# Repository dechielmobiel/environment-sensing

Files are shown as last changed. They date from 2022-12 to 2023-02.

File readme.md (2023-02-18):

<p align="center">
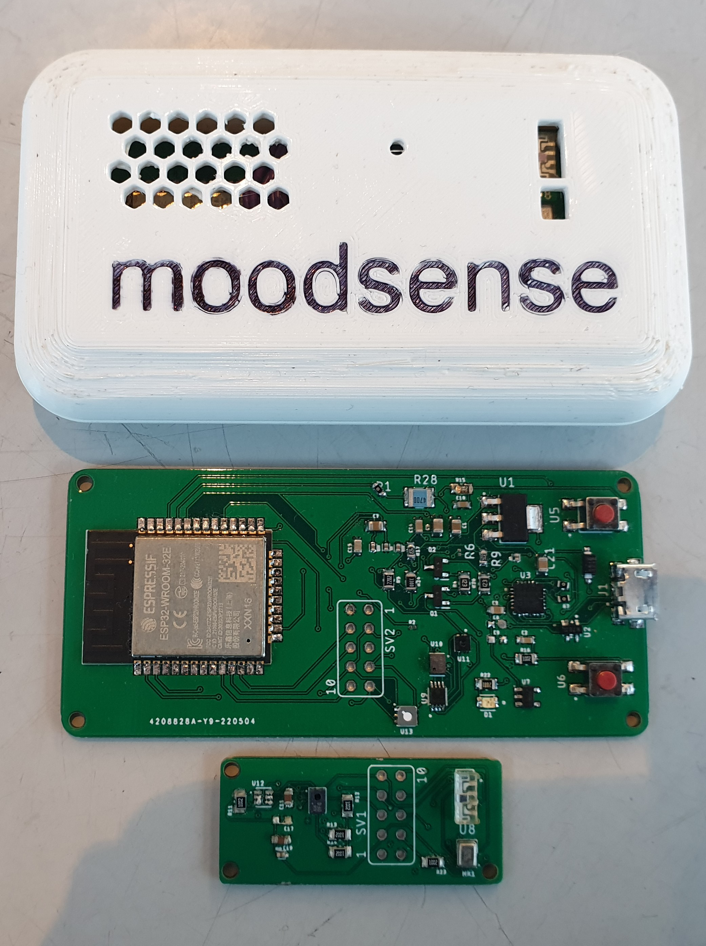
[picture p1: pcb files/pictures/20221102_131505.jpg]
  
</p>

# Environment-sensing
this repository contains all the code and hardware designs for a environmental sensing device that measures environmental paramaters like: illuminance, VOC's, Co2, 11 channel collour, sound, humdidity, temperature and atmospheric pressure, then you can employ tinyML to classify some data with Edge impulse or use a tensorflow model.
# Repesitory contents
- bill of materials 💸
- code 📄
  - Tensorflow Lite
  - Edge impulse
  - Luxpy
  - BLE
  - ESPhome
- mechanical drawings 🔧
  - STL files
  - render pictures
- pcb files 🔋
  - Gerber files
  - project files (schematic + board)
# Prerequisites 
# Hardware
- arduino nano 33 ble sense or ESP32 devkit or ESP-EYE v2.2
- Raspberry pi or linux enabled device 
- Used sensors
  - AS7341 (10 channel color sensor)
  - VEML7700 (lux sensor)
  - SGP30 (Co2 and VOC sensor)
  - DPS310 (air pressure sensor)
  - SHTC3 (temperature and humidity sensor)
  - SPH0645LM4H-1 (I2S mems microphone)
# Software 
- edge impulse cli
- Python (latest stable version)
- tensorflow 2.11
- Jupyter notebook or Jupyter labs
- IDE of choice
  - esp idf (in the case of Tensorflow this is required for use with ESP eye)
  - arduino ide 
  - visual studio code
- git bash
- NumPy
- TensorFlow Hub
- Tensorflow_io 0.28
- nrf connect (Android or IOS)
- (optional)
  - ESPhome
  - Home assistant 
  - InfluxdB
# Edge impulse public projects
- sound classification with ESC-50 (requires a I2S microphone): https://studio.edgeimpulse.com/public/126166/latest/create-impulse
- classify the type of light ( requires AS7341 sensor): https://studio.edgeimpulse.com/studio/54747
# Use esp to capture datapoints for edge impulse
first upload the ...data_aquisition code for example (AS7341_data_aquisition).this code can be editted for your specific sensor.
Then open a commandprompt with edge impulse cli installed and type in the following command.
```cmd
edge-impulse-data-fowarder
```
then the cli will ask you to login to your edge impulse account.
next the cli will ask to wich project you want to connect the device, this can be done by using the arrowkeys.
after this the cli will detect the ammount of sensor axis from the code and asks you to name them, sperated by a comma 
(this has to be done in the exact same order as in the code). 

now you can build your impulse 

# deploy the impulse on a esp32 
the code for the deployment of your impulse on esp32 (or other adruino enabled devices) is based on the data forwarder code and can be modified to work with your sensor just as in the aquisition. To change or upgrade the model you only have to change the inference include file.
here is a example of the code for the AS7341.
```c++
// Include the Arduino library here (something like your_project_inference.h) 
// In the Arduino IDE see **File > Examples > Your project name - Edge Impulse > Static buffer** to get the exact name
#include <zonlicht_vs_kunstlicht_inferencing.h>
#include <Adafruit_AS7341.h>

#define FREQUENCY_HZ        (2)
#define INTERVAL_MS         (1000 / (FREQUENCY_HZ + 1))

Adafruit_AS7341 as7341;
static unsigned long last_interval_ms = 0;
// to classify 1 frame of data you need EI_CLASSIFIER_DSP_INPUT_FRAME_SIZE values
float features[EI_CLASSIFIER_DSP_INPUT_FRAME_SIZE];
// keep track of where we are in the feature array
size_t feature_ix = 0;

void setup() {
    Serial.begin(115200);
    Serial.println("Started");

    if (!as7341.begin()) {
        Serial.println("Failed to initialize AS7341!");
        while (1);
    }
}

void loop() {
    uint16_t readings[12];

    if (millis() > last_interval_ms + INTERVAL_MS) {
        last_interval_ms = millis();

        // read sensor data in exactly the same way as in the Data Forwarder example
         if (!as7341.readAllChannels(readings)){
         Serial.println("Error reading all channels!");
         return;
         }

        // fill the features buffer
        features[feature_ix++] = (readings[0]);
        features[feature_ix++] = (readings[1]);
        features[feature_ix++] = (readings[2]);
        features[feature_ix++] = (readings[3]);
        features[feature_ix++] = (readings[6]);
        features[feature_ix++] = (readings[7]);
        features[feature_ix++] = (readings[8]);
        features[feature_ix++] = (readings[9]);
        features[feature_ix++] = (readings[11]);

        // features buffer full? then classify!
        if (feature_ix == EI_CLASSIFIER_DSP_INPUT_FRAME_SIZE) {
            ei_impulse_result_t result;

            // create signal from features frame
            signal_t signal;
            numpy::signal_from_buffer(features, EI_CLASSIFIER_DSP_INPUT_FRAME_SIZE, &signal);

            // run classifier
            EI_IMPULSE_ERROR res = run_classifier(&signal, &result, false);
            ei_printf("run_classifier returned: %d\n", res);
            if (res != 0) return;

            // print predictions
            ei_printf("Predictions (DSP: %d ms., Classification: %d ms., Anomaly: %d ms.): \n",
                result.timing.dsp, result.timing.classification, result.timing.anomaly);

            // print the predictions
            for (size_t ix = 0; ix < EI_CLASSIFIER_LABEL_COUNT; ix++) {
                ei_printf("%s:\t%.5f\n", result.classification[ix].label, result.classification[ix].value);
            }
        #if EI_CLASSIFIER_HAS_ANOMALY == 1
            ei_printf("anomaly:\t%.3f\n", result.anomaly);
        #endif

            // reset features frame
            feature_ix = 0;
        }
    }
}

void ei_printf(const char *format, ...) {
    static char print_buf[1024] = { 0 };

    va_list args;
    va_start(args, format);
    int r = vsnprintf(print_buf, sizeof(print_buf), format, args);
    va_end(args);

    if (r > 0) {
        Serial.write(print_buf);
    }
}

```
# test the deployment code
to test of the model and code is correct open the static_buffer example in your generated library.
next go to your model in the web editor for example at live classification and load a validated sample and go to detailed results copy the raw feature to paste in the following line of the code:
```c++
static const float features[] = {
    -19.8800, -0.6900, 8.2300, -17.6600, -1.1300, 5.9700, ...
};
```
after this compare the result of the code to the model and if the same the code is working correctly.

# how to use a Tensorflow Lite model on edge devices.
for a full tutorial check the how to use tensorflow with c++.ipynb file for a tutorial on how to use a simple "Hello World" example model and convert it to a C++ tflite model. The example model that uses the ESC-50 dataset to classify cat and dog sounds can be found in the ESC-50.ipynb file.

after you have confirmed this model to be working substitute the model with the sound classifaction model.
To import the ESC-50 model use the following lines. 
```python
_ = tf.keras.utils.get_file('esc-50.zip',
                        'https://github.com/karoldvl/ESC-50/archive/master.zip',
                        cache_dir='./',
                        cache_subdir='datasets',
                        extract=True)
```
allow the model to explore the dataset with the following lines.
```python
esc50_csv = './datasets/ESC-50-master/meta/esc50.csv'
base_data_path = './datasets/ESC-50-master/audio/'

pd_data = pd.read_csv(esc50_csv)
pd_data.head()
```
Lastly choose the labels/classes you want to use and specify the correct class id which can be found in the metadata file in the ESC-50 directory.
for example the class id's for the classes i used are: 
```python
my_classes = ['coughing', 'snoring','sneezing', 'vacuum cleaner', 'train', 'thunderstorm' ]
map_class_to_id = {'coughing':24, 'snoring':28, 'sneezing':21, 'vacuum cleaner':36, 'train':45, 'thunderstorm':19}
```
If you want to use my classes copy and paste the lines above in the ESC-50 example lines below. 
```python
my_classes = ['dog', 'cat']
map_class_to_id = {'dog':0, 'cat':1}

filtered_pd = pd_data[pd_data.category.isin(my_classes)]

class_id = filtered_pd['category'].apply(lambda name: map_class_to_id[name])
filtered_pd = filtered_pd.assign(target=class_id)

full_path = filtered_pd['filename'].apply(lambda row: os.path.join(base_data_path, row))
filtered_pd = filtered_pd.assign(filename=full_path)

filtered_pd.head(10)
```
# how to convert the Tensorflow yamnet model to a tensorflow Lite model.
```python
# Convert the model to the TensorFlow Lite format without quantization
converter = tf.lite.TFLiteConverter.from_saved_model(MODEL_TF)
model_no_quant_tflite = converter.convert()

# Save the model to disk
open(MODEL_NO_QUANT_TFLITE, "wb").write(model_no_quant_tflite)

# Convert the model to the TensorFlow Lite format with quantization
def representative_dataset():
  for i in range(500):
    yield([x_train[i].reshape(1, 1)])
# Set the optimization flag.
converter.optimizations = [tf.lite.Optimize.DEFAULT]
# Enforce integer only quantization
converter.target_spec.supported_ops = [tf.lite.OpsSet.TFLITE_BUILTINS_INT8]
converter.inference_input_type = tf.int8
converter.inference_output_type = tf.int8
# Provide a representative dataset to ensure we quantize correctly.
converter.representative_dataset = representative_dataset
model_tflite = converter.convert()

# Save the model to disk
open(MODEL_TFLITE, "wb").write(model_tflite)
```
After this compare the result of the newly generated model to the original see: https://github.com/dechielmobiel/environment-sensing/blob/main/how%20to%20use%20tensorflow%20with%20c%2B%2B.ipynb for more information. 
# how to convert the model to Tensorflow Lite C++ library.
Convert the TensorFlow Lite quantized model into a C source file that can be loaded by TensorFlow Lite for Microcontrollers.

```python
# Install xxd if it is not available
!apt-get update && apt-get -qq install xxd
# Convert to a C source file, i.e, a TensorFlow Lite for Microcontrollers model
!xxd -i {MODEL_TFLITE} > {MODEL_TFLITE_MICRO}
# Update variable names
REPLACE_TEXT = MODEL_TFLITE.replace('/', '_').replace('.', '_')
!sed -i 's/'{REPLACE_TEXT}'/g_model/g' {MODEL_TFLITE_MICRO} 
```
# deploy your model 
To use your model with ESP32 run the folowing commands:
```python
make -f tensorflow/lite/micro/tools/make/Makefile third_party_downloads
make -f tensorflow/lite/micro/tools/make/Makefile "your_model.cc"
```

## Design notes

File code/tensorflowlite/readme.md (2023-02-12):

To get Tensorflow Lite running on a ESP32 follow the tutorial to on how use the "Hello World" example on microcontrollers see: (how to setup hello world example and convert to C++.ipynb).

Once this is working move on to use the Yamnet sound classification model and how to use it with the ESC-50 datset see: (ESC-50.ipynb).

To change the classes you want to use see the tutorial in the main readme.

the classes that can be used can be found in the ESC-50 metadata file.

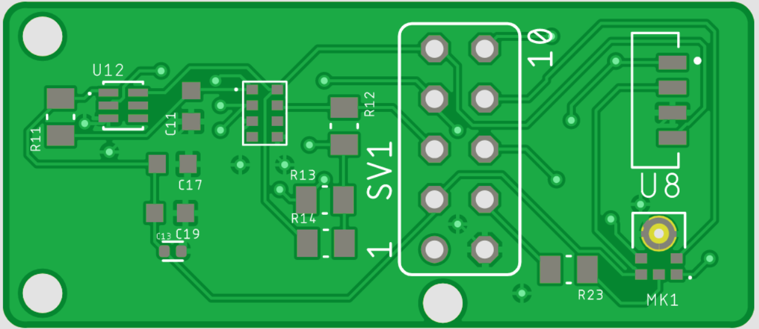
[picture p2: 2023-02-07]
pcb files/pictures/board 2.1.PNG

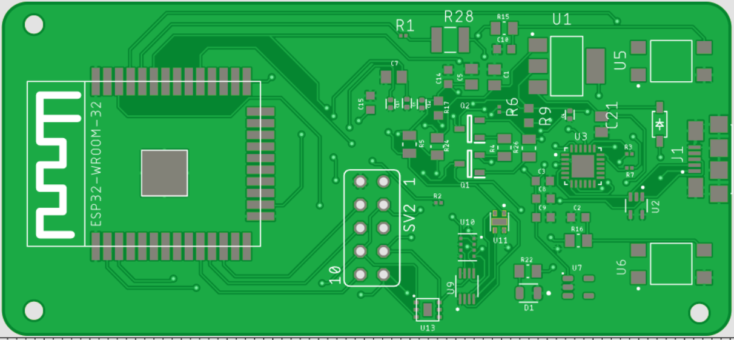
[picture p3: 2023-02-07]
pcb files/pictures/board 3.1.PNG

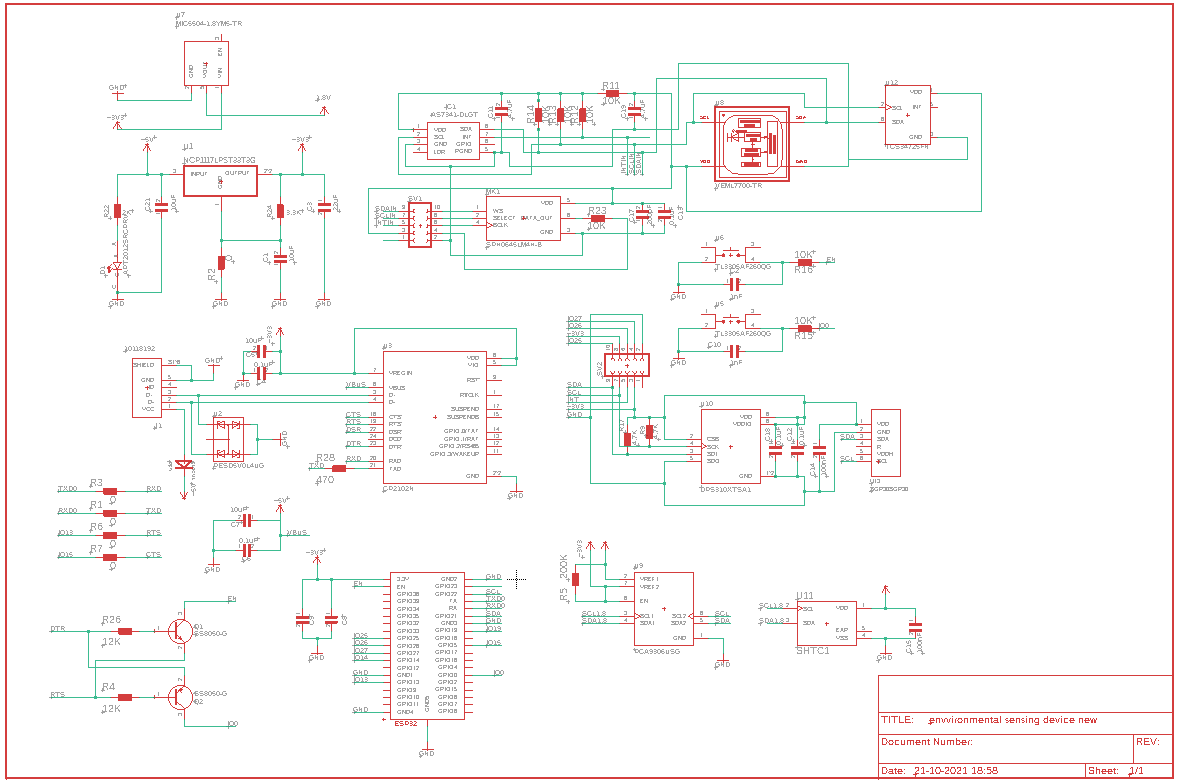
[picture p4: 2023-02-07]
pcb files/pictures/eigen pcb schema.PNG

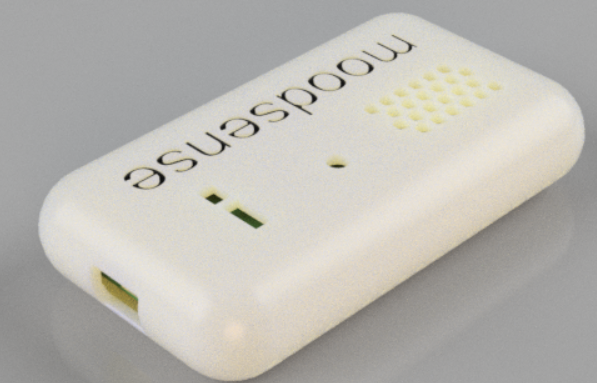
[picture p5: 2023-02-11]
cad files/photo's/isometrisch behuizing.PNG

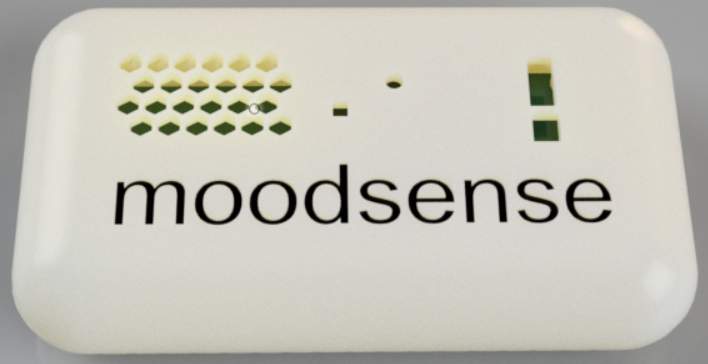
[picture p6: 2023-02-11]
cad files/photo's/moosense behuizing.PNG

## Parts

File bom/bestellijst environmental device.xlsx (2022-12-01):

component | functie | smd/tht | montagetype | stuk prijs | aantal | totaal prijs
AS7341-DLGT | spd meting | smd | OLGA-8 | €6.830 | 5 | €34.15
DPS310XTSA1 | luchtdruk meting | smd | LGA-8 | €3.190 | 5 | €15.95
SHTC3-10k | temperatuur & luchtvochtigheid | smd | DFN-4 | €2.940 | 5 | €14.70
VEML7700-TT | lux meting | smd | SMT | €1.940 | 5 | €9.70
SGP30-2.5k | VOC en Eco2 metingen | smd | DFN-6 | €12.500 | 5 | €62.50
SPH0641LM4H-1 | microfoon | smd | QFN | €0.855 | 5 | €4.28
PESD5V0L4UG,115 | electronic discharge onderdrukking | smd | TSSOP-5 | €0.428 | 5 | €2.14
PCA9306USG | I2C level shifter 3.3v-1.8v, 100Kbit/s - 400Kbit/s | smd | US-8 | €0.840 | 5 | €4.20
SS8050-G | biplolaire transisoren | smd | SOT-23-3 | €0.190 | 10 | €1.90
ESP32-WROOM-32E-N8 | microcontroller + bluetooth & wifi interface | smd | QFN | €3.000 | 5 | €15.00
NCP1117LPST33T3G | voltage regulator 3.3V | smd | SOT-223-3 | €0.420 | 5 | €2.10
MIC5504-1.8YM5-TR | voltage regulator 1.8V | smd | SOT-23-5 | €0.150 | 5 | €0.75
CP2102N-A02-GQFN24R | Usb to uart controller | smd | GFN24 | €1.970 | 5 | €9.85
10118192-0001LF | Micro USB type B 5P | smd | nvt | €0.419 | 5 | €2.09
1N5819 | Schotky diode | tht | nvt | €0.364 | 5 | €1.82
TL3305AF260QG | tactile switch | smd | nvt | €0.183 | 10 | €1.83
505110-1092 | FFC connector 10 pins | smd | nvt | €0.549 | 10 | €5.49
15016-0101 | FFC kabel 10 posities | nvt | nvt | €2.370 | 5 | €11.85
nvt | condensator 100nF | smd | 0402 | €0.045 | 20 | €0.90
nvt | condensator 100nF | smd | 0603 | €0.245 | 10 | €2.45
nvt | weerstand 4,7KΩ | smd | 0603 | €0.065 | 10 | €0.65
nvt | condensator 4,7uF | smd | 0603 | €0.445 | 10 | €4.45
nvt | weerstand 10KΩ | smd | 0805 | €0.075 | 30 | €2.25
nvt | weerstand 12KΩ | smd | 0805 | €0.075 | 10 | €0.75
nvt | weerstand 3,3KΩ | smd | 0805 | €0.075 | 10 | €0.75
nvt | weerstand 470Ω | smd | 1206 | €0.075 | 10 | €0.75
nvt | smd soldeerpasta | nvt | nvt | €6.450 | 1 | €6.45
nvt | led groen 589nm | smd | nvt | €0.075 | 10 | €0.75
nvt | condensator 22uF | smd | 0603 | €0.077 | 50 | €3.86
nvt | condensator 10uF | smd | 0805 | €0.043 | 50 | €2.14
nvt | pincet voor assemblage | nvt | nvt | €4.480 | 1 | €4.48
nvt | weerstand 470Ω | smd | 1210 | €0.244 | 5 | €1.22
nvt | weerstand 0Ω jumper | smd | 0603 | €0.033 | 30 | €0.98
nvt | weerstand 2KΩ | smd | 0805 | €0.333 | 10 | €3.33
nvt | weerstand 22KΩ | smd | 0805 | €0.082 | 20 | €1.64
nvt | condensator 1nF | smd | 0603 | €0.095 | 10 | €0.95
 |  |  |  |  | totaal: | €239.05
 |  |  |  |  | verzending: | gratis

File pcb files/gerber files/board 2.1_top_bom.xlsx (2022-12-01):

Comment | Designator | Footprint | JLCPCB Part #（optional）
0.1uF | C13 | CAPC1005X55N
4.7uF | C11 C19 | CAPC1608X90N
10K | R11 R12 R13 R14 R23 | RESC2012X70N
200pF | C17 | CAPC1608X90N
AS7341-DLGT | IC1 | AS7341DLGT
SPH0645LM4H-B | MK1 | MIC_SPH0645LM4H-B
TCS34725FN | U12 | SON65P200X240X70-6N
VEML7700-TR | U8 | XDCR_VEML7700-TR

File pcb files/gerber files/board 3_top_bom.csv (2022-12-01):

Comment | Designator | Footprint | LCSC Part #
0 | R1 R2 R3 R6 R7 | RESC0603X26N
0.1uF | C4 C6 C12 C18 | CAPC1005X55N
1N5819 | U$2 | SOD-123
1nF | C2 C10 | CAPC1608X90N
2K | R22 | RESC2012X70N
3.3K | R24 | RESC2012X70N
4.7K | R9 R17 | RESC1608X55N
10K | R15 R16 | RESC2012X70N
10uF | C1 C5 C7 C21 | CAPC2012X135N
12K | R4 R26 | RESC2012X75N
22uF | C3 | CAPC1608X90N
100nF | C14 C15 | CAPC1608X90N
100uF 6.3V 20% | C9 | CAPC1608X90N
200K | R5 | RESC2012X75N
470 | R28 | RESC3225X70N
10118192 | J1 | AMPHENOL_10118192-0002LF
APT2012SRCPRV | D1 | LEDC2012X75N
CL10A475KQ8NNNC | C8 | CAPC1608X90N
CP2102N | U3 | QFN50P400X400X80-25N
DPS310XTSA1 | U10 | XDCR_DPS310XTSA1
ESP32-WROOM | U$1 | ESP32-WROOM
MIC5504-1.8YM5-TR | U7 | SOT23-5P95_280X145XL45X37N
NCP1117LPST33T3G | U1 | SOT230P700X175-4N
PCA9306USG | U9 | SOP50P310X90-8N
PESD5V0L4UG | U2 | SOT65P210X110-5N
SGP30SGP30 | U13 | SGP30
SHTC1 | U11 | XDCR_SHTC1
SS8050-G | Q1 Q2 | SOT95P240X115-3N
TL3305AF260QG | U5 U6 | SW_TL3305AF260QG

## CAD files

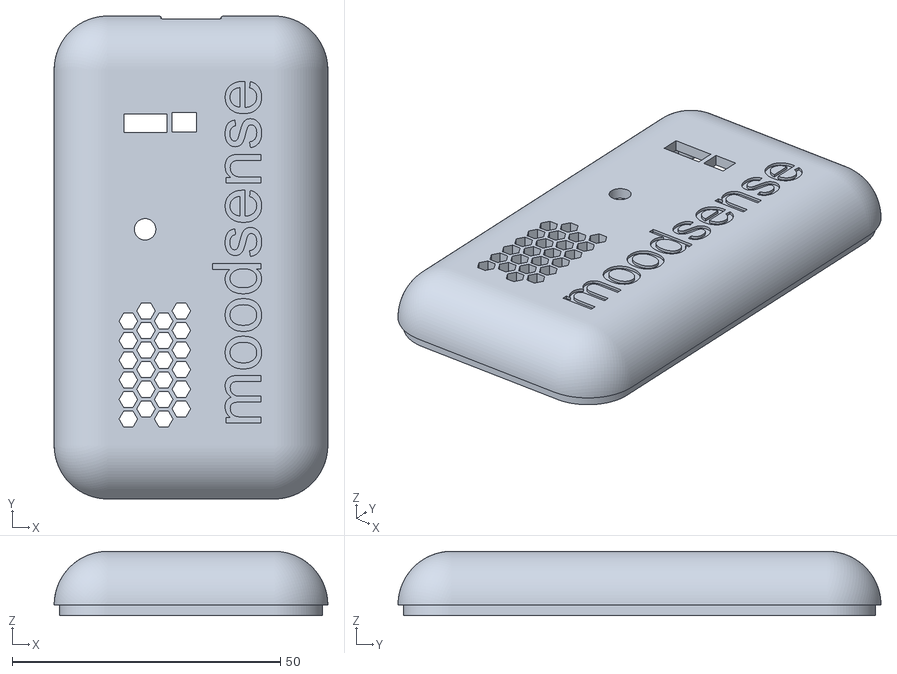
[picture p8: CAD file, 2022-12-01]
cad files/moodsense boven.stl
51.0 x 90.0 x 12.0

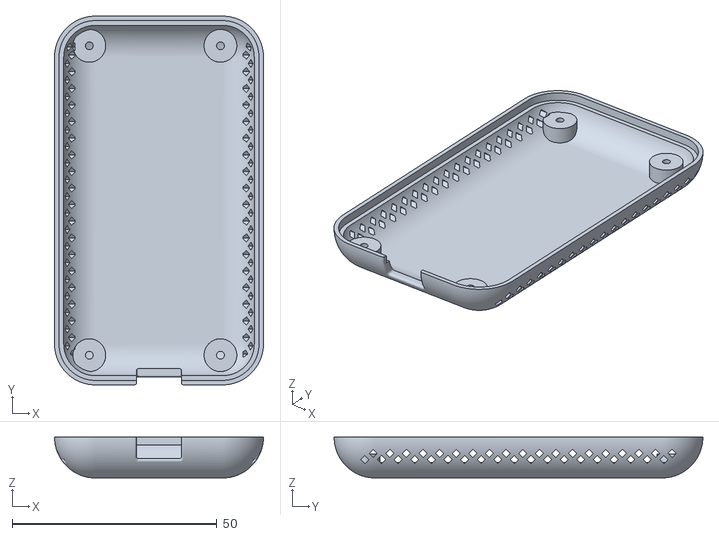
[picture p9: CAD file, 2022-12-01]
cad files/modsense onder.stl
51.0 x 90.0 x 10.0

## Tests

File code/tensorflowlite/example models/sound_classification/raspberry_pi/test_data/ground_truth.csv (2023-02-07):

label | score
Cat | 0.73828125
Animal | 0.66796875
Domestic animals, pets | 0.66796875
Meow | 0.4140625
Caterwaul | 0.33203125

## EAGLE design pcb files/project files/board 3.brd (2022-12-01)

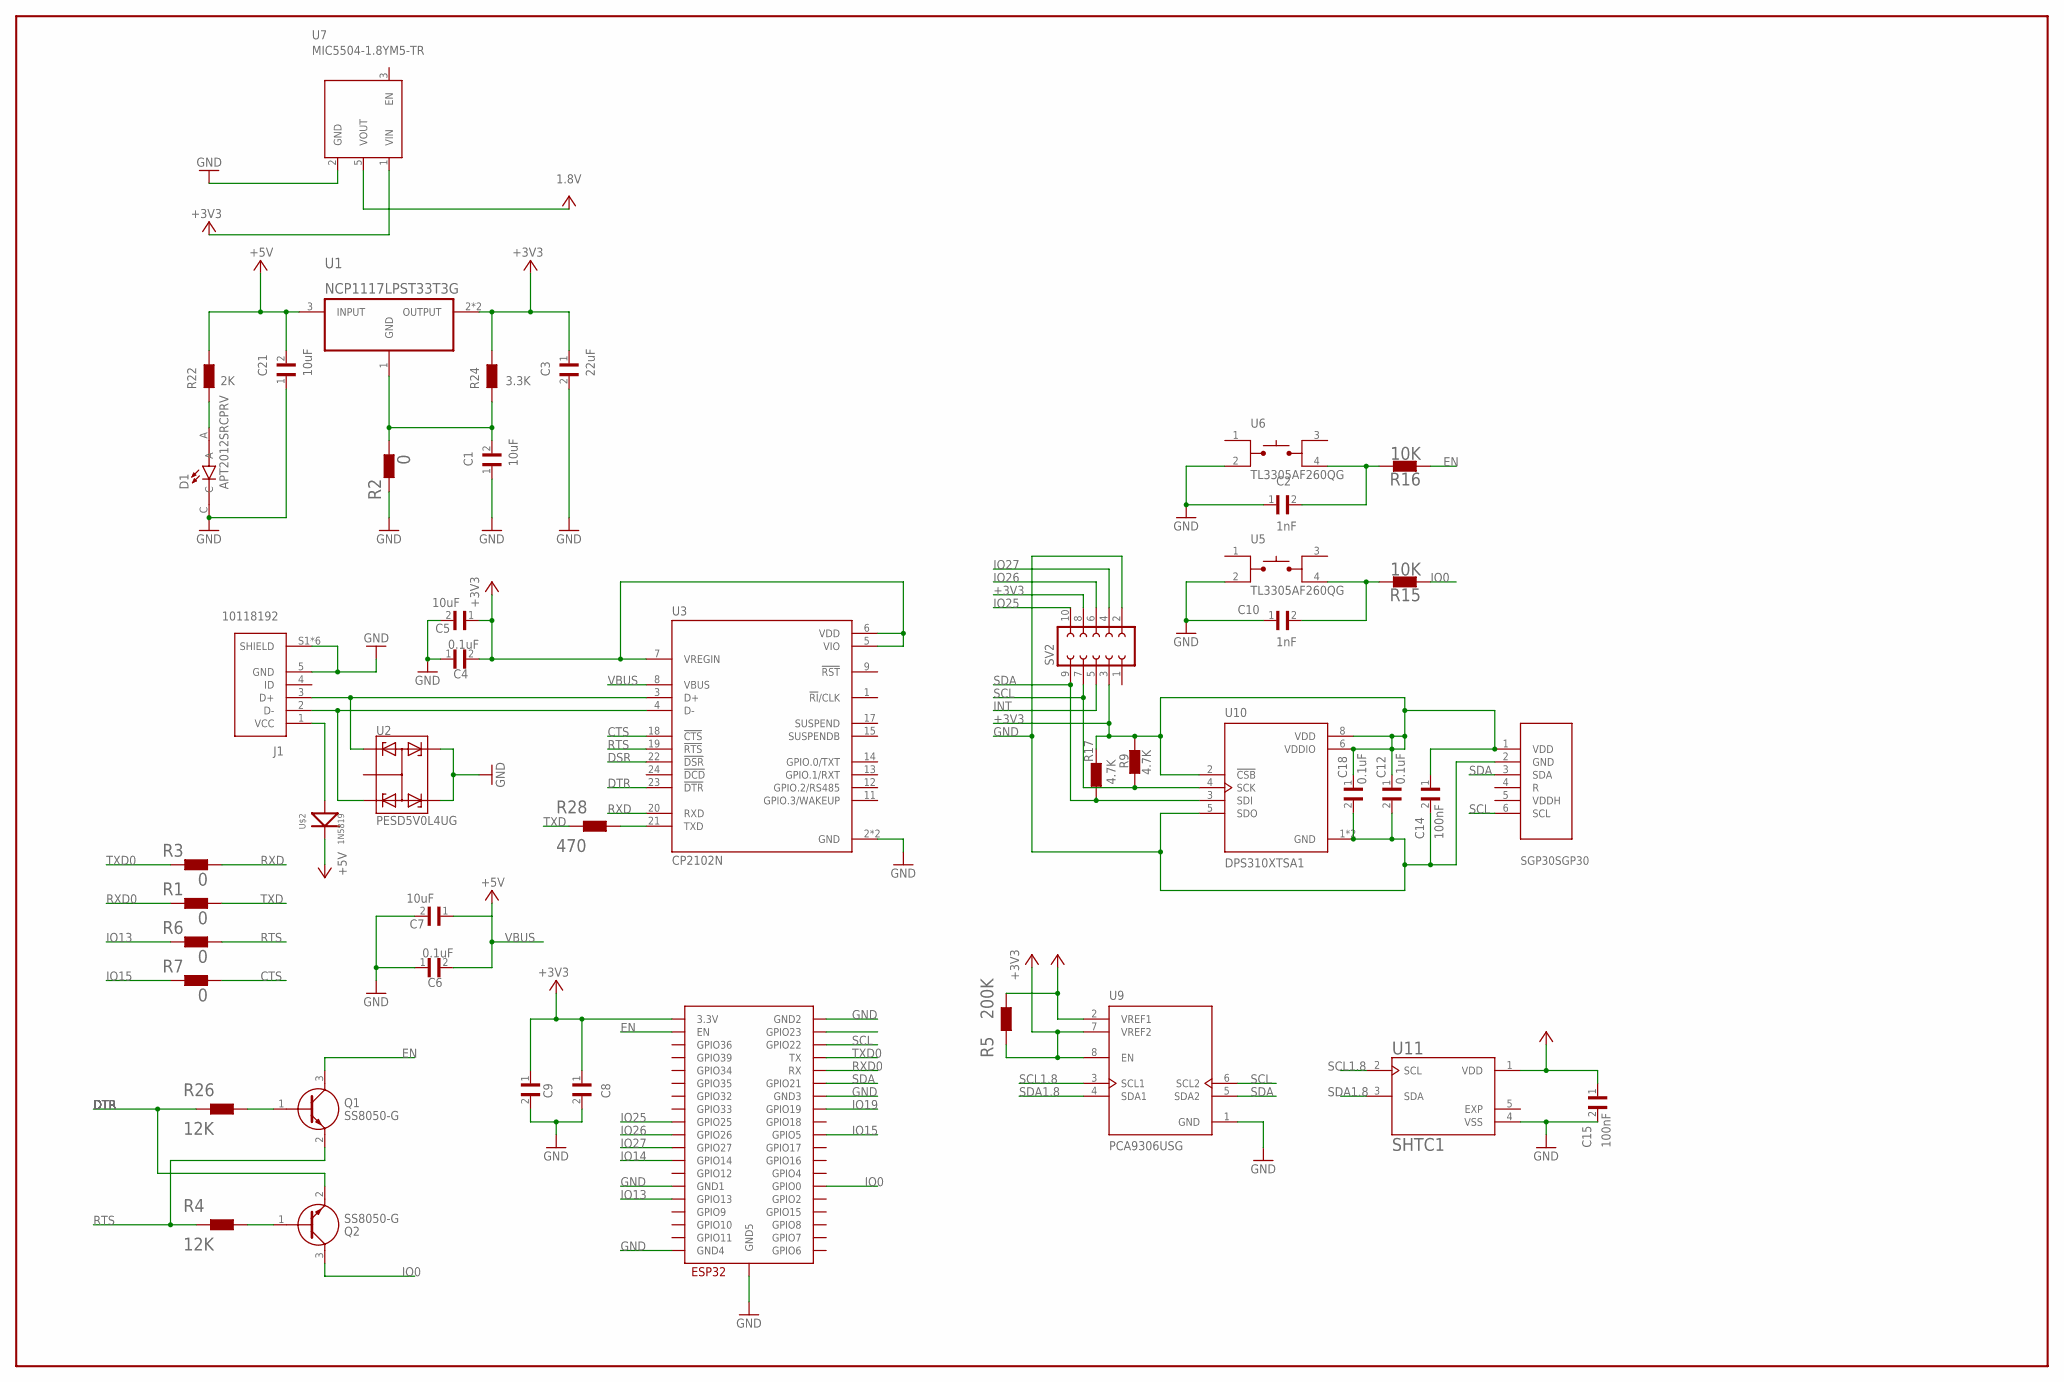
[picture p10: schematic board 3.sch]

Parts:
C1, C5, C7, C21: 10uF; CAPC2012X135N
C2, C10: 1nF; CAPC1608X90N
C3: 22uF; CAPC1608X90N
C4, C6, C12, C18: 0.1uF; CAPC1005X55N
C8: CL10A475KQ8NNNC; CAPC1608X90N
C9: 100uF 6.3V 20%; CAPC1608X90N
C14, C15: 100nF; CAPC1608X90N
D1: APT2012SRCPRV; LEDC2012X75N
J1: 10118192; AMPHENOL_10118192-0002LF
Q1, Q2: SS8050-G; SOT95P240X115-3N
R1, R2, R3, R6, R7: 0; RESC0603X26N
R4, R26: 12K; RESC2012X75N
R5: 200K; RESC2012X75N
R9, R17: 4.7K; RESC1608X55N
R15, R16: 10K; RESC2012X70N
R22: 2K; RESC2012X70N
R24: 3.3K; RESC2012X70N
R28: 470; RESC3225X70N
SV2: FE05-2
U1: NCP1117LPST33T3G; SOT230P700X175-4N
U2: PESD5V0L4UG; SOT65P210X110-5N
U3: CP2102N; QFN50P400X400X80-25N
U5, U6: TL3305AF260QG; SW_TL3305AF260QG
U7: MIC5504-1.8YM5-TR; SOT23-5P95_280X145XL45X37N
U9: PCA9306USG; SOP50P310X90-8N
U10: DPS310XTSA1; XDCR_DPS310XTSA1
U11: SHTC1; XDCR_SHTC1
U13: SGP30SGP30; SGP30
U$1: ESP32-WROOM
U$2: 1N5819; SOD-123

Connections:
1.8V: U7.5 (VOUT)
+3V3: C3.1, C4.2, C5.1, C8.1, C9.1, C12.1, C14.1, C18.1, R5.1, R9.2, R17.2, R24.2, SV2.3, SV2.8, U1.2 (OUTPUT), U1.4 (OUTPUT), U3.5 (VIO), U3.6 (VDD), U3.7 (VREGIN), U7.1 (VIN), U9.7 (VREF2), U9.8 (EN), U10.2 (!CSB), U10.6 (VDDIO), U10.8 (VDD), U13.1 (VDD), U$1.3V3 (3.3V)
+5V: C21.2, R22.2, U1.3 (INPUT), U$2.K
CTS: R7.2, U3.18 (!CTS)
DSR: U3.22 (!DSR)
DTR: Q2.2 (E), R26.1, U3.23 (!DTR)
EN: Q1.3 (C), R16.1, U$1.EN
GND: C1.1, C2.1, C3.2, C4.1, C5.2, C6.1, C7.2, C8.2, C9.2, C10.1, C12.2, C14.2, C15.2, C18.2, C21.1, D1.C, J1.5 (GND), J1.S1 (SHIELD), J1.S2 (SHIELD), J1.S3 (SHIELD), J1.S4 (SHIELD), J1.S5 (SHIELD), J1.S6 (SHIELD), R2.1, SV2.2, U2.4, U2.5, U3.2 (GND), U3.25 (GND), U5.2, U6.2, U7.2 (GND), U9.1 (GND), U10.1 (GND), U10.5 (SDO), U10.7 (GND), U11.4 (VSS), U13.2 (GND), U$1.GND1, U$1.GND2, U$1.GND3, U$1.GND4, U$1.GND5
INT: SV2.5
IO0: Q2.3 (C), R15.1, U$1.IO0 (GPIO0)
IO13: R6.1, U$1.IO13 (GPIO13)
IO14: U$1.IO14 (GPIO14)
IO15: R7.1, U$1.IO5 (GPIO5)
IO19: U$1.IO19 (GPIO19)
IO25: SV2.10, U$1.IO25 (GPIO25)
IO26: SV2.6, U$1.IO26 (GPIO26)
IO27: SV2.4, U$1.IO27 (GPIO27)
unnamed: J1.2 (D-), U2.3, U3.4 (D-)
unnamed: J1.3 (D+), U2.1, U3.3 (D+)
unnamed: J1.1 (VCC), U$2.A
unnamed: R28.2, U3.21 (TXD)
unnamed: D1.A, R22.1
unnamed: C1.2, R2.2, R24.1, U1.1 (GND)
unnamed: Q1.1 (B), R26.2
unnamed: Q2.1 (B), R4.2
unnamed: C2.2, R16.2, U6.4
unnamed: C10.2, R15.2, U5.4
RTS: Q1.2 (E), R4.1, R6.2, U3.19 (!RTS)
RXD: R3.2, U3.20 (RXD)
RXD0: R1.1, U$1.RX
SCL: R9.1, SV2.7, U9.6 (SCL2), U10.4 (SCK), U13.6 (SCL), U$1.IO22 (GPIO22)
SCL1.8: U9.3 (SCL1), U11.2 (SCL)
SDA: R17.1, SV2.9, U9.5 (SDA2), U10.3 (SDI), U13.3 (SDA), U$1.IO21 (GPIO21)
SDA1.8: U9.4 (SDA1), U11.3 (SDA)
TXD: R1.2, R28.1
TXD0: R3.1, U$1.TX
VBUS: C6.2, C7.1, U3.8 (VBUS)
VCC: C15.1, R5.2, U9.2 (VREF1), U11.1 (VDD)

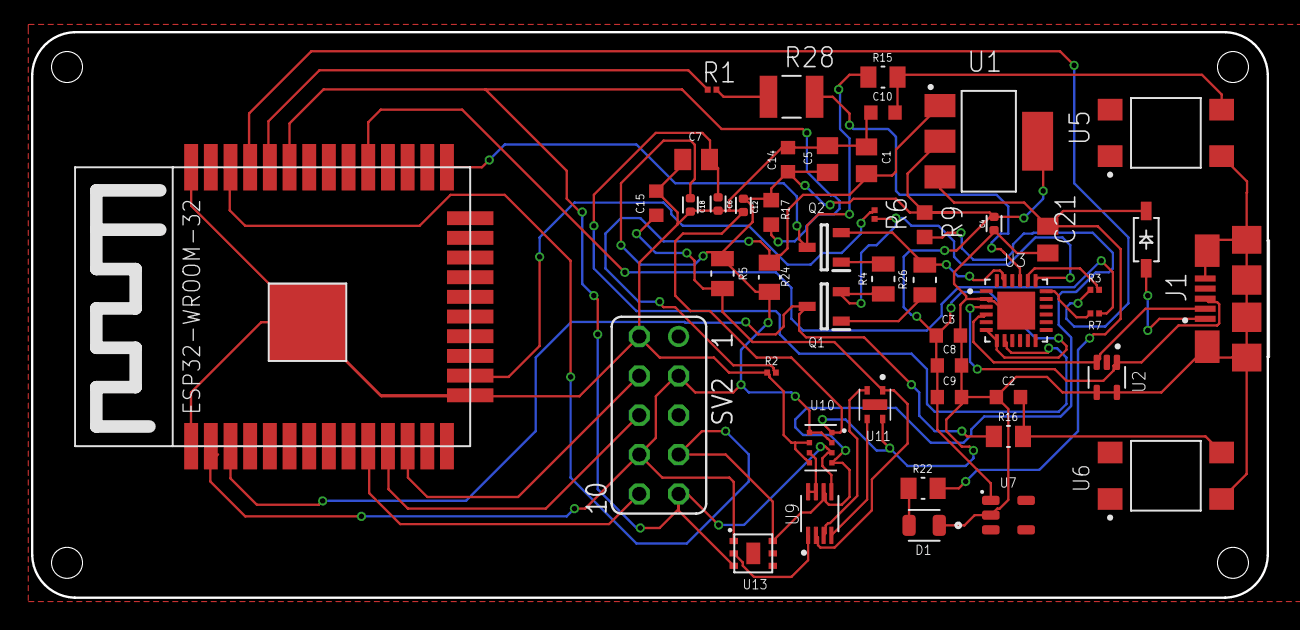
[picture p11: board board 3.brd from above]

Board: 2 copper layers, 79.8 x 36.5 mm, 47 parts (0 on the bottom side), 33 nets.

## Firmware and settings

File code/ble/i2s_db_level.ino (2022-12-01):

#include <driver/i2s.h>
#include "sos-iir-filter.h"

float Leq_dB;

//
// Configuration
//

#define LEQ_PERIOD        1           // second(s)
#define WEIGHTING         C_weighting // Also avaliable: 'C_weighting' or 'None' (Z_weighting)
#define LEQ_UNITS         "LAeq"      // customize based on above weighting used
#define DB_UNITS          "dBA"       // customize based on above weighting used
#define USE_DISPLAY       1

// NOTE: Some microphones require at least DC-Blocker filter
#define MIC_EQUALIZER     SPH0645LM4H_B_RB    // See below for defined IIR filters or set to 'None' to disable
#define MIC_OFFSET_DB     3.0103      // Default offset (sine-wave RMS vs. dBFS). Modify this value for linear calibration

// Customize these values from microphone datasheet
#define MIC_SENSITIVITY   -26         // dBFS value expected at MIC_REF_DB (Sensitivity value from datasheet)
#define MIC_REF_DB        94.0        // Value at which point sensitivity is specified in datasheet (dB)
#define MIC_OVERLOAD_DB   116.0       // dB - Acoustic overload point
#define MIC_NOISE_DB      29          // dB - Noise floor
#define MIC_BITS          24          // valid number of bits in I2S data
#define MIC_CONVERT(s)    (s >> (SAMPLE_BITS - MIC_BITS))
#define MIC_TIMING_SHIFT  1           // Set to one to fix MSB timing for some microphones, i.e. SPH0645LM4H-x

// Calculate reference amplitude value at compile time
constexpr double MIC_REF_AMPL = pow(10, double(MIC_SENSITIVITY)/20) * ((1<<(MIC_BITS-1))-1);

//
// I2S pins - Can be routed to almost any (unused) ESP32 pin.
//            SD can be any pin, inlcuding input only pins (36-39).
//            SCK (i.e. BCLK) and WS (i.e. L/R CLK) must be output capable pins
//
// Below ones are just example for my board layout, put here the pins you will use
//
#define I2S_WS             
#define I2S_SCK           16 
#define I2S_SD            17

// I2S peripheral to use (0 or 1)
#define I2S_PORT          I2S_NUM_0


//
// IIR Filters
//

// DC-Blocker filter - removes DC component from I2S data
// See: https://www.dsprelated.com/freebooks/filters/DC_Blocker.html
// a1 = -0.9992 should heavily attenuate frequencies below 10Hz
SOS_IIR_Filter DC_BLOCKER = { 
  gain: 1.0,
  sos: {{-1.0, 0.0, +0.9992, 0}}
};

// 
// Equalizer IIR filters to flatten microphone frequency response
// See respective .m file for filter design. Fs = 48Khz.
//
// Filters are represented as Second-Order Sections cascade with assumption
// that b0 and a0 are equal to 1.0 and 'gain' is applied at the last step 
// B and A coefficients were transformed with GNU Octave: 
// [sos, gain] = tf2sos(B, A)
// See: https://www.dsprelated.com/freebooks/filters/Series_Second_Order_Sections.html
// NOTE: SOS matrix 'a1' and 'a2' coefficients are negatives of tf2sos output
//

// TDK/InvenSense ICS-43434
// Datasheet: https://www.invensense.com/wp-content/uploads/2016/02/DS-000069-ICS-43434-v1.1.pdf
// B = [0.477326418836803, -0.486486982406126, -0.336455844522277, 0.234624646917202, 0.111023257388606];
// A = [1.0, -1.93073383849136326, 0.86519456089576796, 0.06442838283825100, 0.00111249298800616];
SOS_IIR_Filter ICS43434 = { 
  gain: 0.477326418836803,
  sos: { // Second-Order Sections {b1, b2, -a1, -a2}
   {+0.96986791463971267, 0.23515976355743193, -0.06681948004769928, -0.00111521990688128},
   {-1.98905931743624453, 0.98908924206960169, +1.99755331853906037, -0.99755481510122113}
  }
};

// TDK/InvenSense ICS-43432
// Datasheet: https://www.invensense.com/wp-content/uploads/2015/02/ICS-43432-data-sheet-v1.3.pdf
// B = [-0.45733702338341309   1.12228667105574775  -0.77818278904413563, 0.00968926337978037, 0.10345668405223755]
// A = [1.0, -3.3420781082912949, 4.4033694320978771, -3.0167072679918010, 1.2265536567647031, -0.2962229189311990, 0.0251085747458112]
SOS_IIR_Filter ICS43432 = {
  gain: -0.457337023383413,
  sos: { // Second-Order Sections {b1, b2, -a1, -a2}
    {-0.544047931916859, -0.248361759321800, +0.403298891662298, -0.207346186351843},
    {-1.909911869441421, +0.910830292683527, +1.790285722826743, -0.804085812369134},
    {+0.000000000000000, +0.000000000000000, +1.148493493802252, -0.150599527756651}
  }
};

// TDK/InvenSense INMP441
// Datasheet: https://www.invensense.com/wp-content/uploads/2015/02/INMP441.pdf
// B ~= [1.00198, -1.99085, 0.98892]
// A ~= [1.0, -1.99518, 0.99518]
SOS_IIR_Filter INMP441 = {
  gain: 1.00197834654696, 
  sos: { // Second-Order Sections {b1, b2, -a1, -a2}
    {-1.986920458344451, +0.986963226946616, +1.995178510504166, -0.995184322194091}
  }
};

// Infineon IM69D130 Shield2Go
// Datasheet: https://www.infineon.com/dgdl/Infineon-IM69D130-DS-v01_00-EN.pdf?fileId=5546d462602a9dc801607a0e46511a2e
// B ~= [1.001240684967527, -1.996936108836337, 0.995703101823006]
// A ~= [1.0, -1.997675693595542, 0.997677044195563]
// With additional DC blocking component
SOS_IIR_Filter IM69D130 = {
  gain: 1.00124068496753,
  sos: {
    {-1.0, 0.0, +0.9992, 0}, // DC blocker, a1 = -0.9992
    {-1.994461610298131, 0.994469278738208, +1.997675693595542, -0.997677044195563}
  }
};

// Knowles SPH0645LM4H-B, rev. B
// https://cdn-shop.adafruit.com/product-files/3421/i2S+Datasheet.PDF
// B ~= [1.001234, -1.991352, 0.990149]
// A ~= [1.0, -1.993853, 0.993863]
// With additional DC blocking component
SOS_IIR_Filter SPH0645LM4H_B_RB = {
  gain: 1.00123377961525, 
  sos: { // Second-Order Sections {b1, b2, -a1, -a2}
    {-1.0, 0.0, +0.9992, 0}, // DC blocker, a1 = -0.9992
    {-1.988897663539382, +0.988928479008099, +1.993853376183491, -0.993862821429572}
  }
};

//
// Weighting filters
//

//
// A-weighting IIR Filter, Fs = 48KHz 
// (By Dr. Matt L., Source: https://dsp.stackexchange.com/a/36122)
// B = [0.169994948147430, 0.280415310498794, -1.120574766348363, 0.131562559965936, 0.974153561246036, -0.282740857326553, -0.152810756202003]
// A = [1.0, -2.12979364760736134, 0.42996125885751674, 1.62132698199721426, -0.96669962900852902, 0.00121015844426781, 0.04400300696788968]
SOS_IIR_Filter A_weighting = {
  gain: 0.169994948147430, 
  sos: { // Second-Order Sections {b1, b2, -a1, -a2}
    {-2.00026996133106, +1.00027056142719, -1.060868438509278, -0.163987445885926},
    {+4.35912384203144, +3.09120265783884, +1.208419926363593, -0.273166998428332},
    {-0.70930303489759, -0.29071868393580, +1.982242159753048, -0.982298594928989}
  }
};

//
// C-weighting IIR Filter, Fs = 48KHz 
// Designed by invfreqz curve-fitting, see respective .m file
// B = [-0.49164716933714026, 0.14844753846498662, 0.74117815661529129, -0.03281878334039314, -0.29709276192593875, -0.06442545322197900, -0.00364152725482682]
// A = [1.0, -1.0325358998928318, -0.9524000181023488, 0.8936404694728326   0.2256286147169398  -0.1499917107550188, 0.0156718181681081]
SOS_IIR_Filter C_weighting = {
  gain: -0.491647169337140,
  sos: { 
    {+1.4604385758204708, +0.5275070373815286, +1.9946144559930252, -0.9946217070140883},
    {+0.2376222404939509, +0.0140411206016894, -1.3396585608422749, -0.4421457807694559},
    {-2.0000000000000000, +1.0000000000000000, +0.3775800047420818, -0.0356365756680430}
  }
};


//
// Sampling
//
#define SAMPLE_RATE       48000 // Hz, fixed to design of IIR filters
#define SAMPLE_BITS       32    // bits
#define SAMPLE_T          int32_t 
#define SAMPLES_SHORT     (SAMPLE_RATE / 8) // ~125ms
#define SAMPLES_LEQ       (SAMPLE_RATE * LEQ_PERIOD)
#define DMA_BANK_SIZE     (SAMPLES_SHORT / 16)
#define DMA_BANKS         32

// Data we push to 'samples_queue'
struct sum_queue_t {
  // Sum of squares of mic samples, after Equalizer filter
  float sum_sqr_SPL;
  // Sum of squares of weighted mic samples
  float sum_sqr_weighted;
  // Debug only, FreeRTOS ticks we spent processing the I2S data
  uint32_t proc_ticks;
};
QueueHandle_t samples_queue;

// Static buffer for block of samples
float samples[SAMPLES_SHORT] __attribute__((aligned(4)));

//
// I2S Microphone sampling setup 
//
void mic_i2s_init() {
  // Setup I2S to sample mono channel for SAMPLE_RATE * SAMPLE_BITS
  // NOTE: Recent update to Arduino_esp32 (1.0.2 -> 1.0.3)
  //       seems to have swapped ONLY_LEFT and ONLY_RIGHT channels
  const i2s_config_t i2s_config = {
    mode: i2s_mode_t(I2S_MODE_MASTER | I2S_MODE_RX),
    sample_rate: SAMPLE_RATE,
    bits_per_sample: i2s_bits_per_sample_t(SAMPLE_BITS),
    channel_format: I2S_CHANNEL_FMT_ONLY_LEFT,
    communication_format: i2s_comm_format_t(I2S_COMM_FORMAT_I2S | I2S_COMM_FORMAT_I2S_MSB),
    intr_alloc_flags: ESP_INTR_FLAG_LEVEL1,
    dma_buf_count: DMA_BANKS,
    dma_buf_len: DMA_BANK_SIZE,
    use_apll: true,
    tx_desc_auto_clear: false,
    fixed_mclk: 0
  };
  // I2S pin mapping
  const i2s_pin_config_t pin_config = {
    bck_io_num:   I2S_SCK,  
    ws_io_num:    I2S_WS,    
    data_out_num: -1, // not used
    data_in_num:  I2S_SD   
  };

  i2s_driver_install(I2S_PORT, &i2s_config, 0, NULL);

  #if (MIC_TIMING_SHIFT > 0) 
    // Undocumented (?!) manipulation of I2S peripheral registers
    // to fix MSB timing issues with some I2S microphones
    REG_SET_BIT(I2S_TIMING_REG(I2S_PORT), BIT(9));   
    REG_SET_BIT(I2S_CONF_REG(I2S_PORT), I2S_RX_MSB_SHIFT);  
  #endif
  
  i2s_set_pin(I2S_PORT, &pin_config);

  //FIXME: There is a known issue with esp-idf and sampling rates, see:
  //       https://github.com/espressif/esp-idf/issues/2634
  //       In the meantime, the below line seems to set sampling rate at ~47999.992Hz
  //       fifs_req=24576000, sdm0=149, sdm1=212, sdm2=5, odir=2 -> fifs_reached=24575996  
  //NOTE:  This seems to be fixed in ESP32 Arduino 1.0.4, esp-idf 3.2
  //       Should be safe to remove...
  //#include <soc/rtc.h>
  //rtc_clk_apll_enable(1, 149, 212, 5, 2);
}

//
// I2S Reader Task
//
// Rationale for separate task reading I2S is that IIR filter
// processing cam be scheduled to different core on the ESP32
// while main task can do something else, like update the 
// display in the example
//
// As this is intended to run as separate hihg-priority task, 
// we only do the minimum required work with the I2S data
// until it is 'compressed' into sum of squares 
//
// FreeRTOS priority and stack size (in 32-bit words) 
#define I2S_TASK_PRI   4
#define I2S_TASK_STACK 2048
//
void mic_i2s_reader_task(void* parameter) {
  mic_i2s_init();

  // Discard first block, microphone may have startup time (i.e. INMP441 up to 83ms)
  size_t bytes_read = 0;
  i2s_read(I2S_PORT, &samples, SAMPLES_SHORT * sizeof(int32_t), &bytes_read, portMAX_DELAY);

  while (true) {
    // Block and wait for microphone values from I2S
    //
    // Data is moved from DMA buffers to our 'samples' buffer by the driver ISR
    // and when there is requested ammount of data, task is unblocked
    //
    // Note: i2s_read does not care it is writing in float[] buffer, it will write
    //       integer values to the given address, as received from the hardware peripheral. 
    i2s_read(I2S_PORT, &samples, SAMPLES_SHORT * sizeof(SAMPLE_T), &bytes_read, portMAX_DELAY);

    TickType_t start_tick = xTaskGetTickCount();
    
    // Convert (including shifting) integer microphone values to floats, 
    // using the same buffer (assumed sample size is same as size of float), 
    // to save a bit of memory
    SAMPLE_T* int_samples = (SAMPLE_T*)&samples;
    for(int i=0; i<SAMPLES_SHORT; i++) samples[i] = MIC_CONVERT(int_samples[i]);

    sum_queue_t q;
    // Apply equalization and calculate Z-weighted sum of squares, 
    // writes filtered samples back to the same buffer.
    q.sum_sqr_SPL = MIC_EQUALIZER.filter(samples, samples, SAMPLES_SHORT);

    // Apply weighting and calucate weigthed sum of squares
    q.sum_sqr_weighted = WEIGHTING.filter(samples, samples, SAMPLES_SHORT);

    // Debug only. Ticks we spent filtering and summing block of I2S data
    q.proc_ticks = xTaskGetTickCount() - start_tick;

    // Send the sums to FreeRTOS queue where main task will pick them up
    // and further calcualte decibel values (division, logarithms, etc...)
    xQueueSend(samples_queue, &q, portMAX_DELAY);
  }
}

//
// Setup and main loop 
//
// Note: Use doubles, not floats, here unless you want to pin
//       the task to whichever core it happens to run on at the moment
// 
void setup() {

  // If needed, now you can actually lower the CPU frquency,
  // i.e. if you want to (slightly) reduce ESP32 power consumption 
  setCpuFrequencyMhz(80); // It should run as low as 80MHz
  
  Serial.begin(112500);
  delay(1000); // Safety
  


  // Create FreeRTOS queue
  samples_queue = xQueueCreate(8, sizeof(sum_queue_t));
  
  // Create the I2S reader FreeRTOS task
  // NOTE: Current version of ESP-IDF will pin the task 
  //       automatically to the first core it happens to run on
  //       (due to using the hardware FPU instructions).
  //       For manual control see: xTaskCreatePinnedToCore
  xTaskCreate(mic_i2s_reader_task, "Mic I2S Reader", I2S_TASK_STACK, NULL, I2S_TASK_PRI, NULL);

  sum_queue_t q;
  uint32_t Leq_samples = 0;
  double Leq_sum_sqr = 0;
  double Leq_dB = 0;

  // Read sum of samaples, calculated by 'i2s_reader_task'
  while (xQueueReceive(samples_queue, &q, portMAX_DELAY)) {

    // Calculate dB values relative to MIC_REF_AMPL and adjust for microphone reference
    double short_RMS = sqrt(double(q.sum_sqr_SPL) / SAMPLES_SHORT);
    double short_SPL_dB = MIC_OFFSET_DB + MIC_REF_DB + 20 * log10(short_RMS / MIC_REF_AMPL);

    // In case of acoustic overload or below noise floor measurement, report infinty Leq value
    if (short_SPL_dB > MIC_OVERLOAD_DB) {
      Leq_sum_sqr = INFINITY;
    } else if (isnan(short_SPL_dB) || (short_SPL_dB < MIC_NOISE_DB)) {
      Leq_sum_sqr = -INFINITY;
    }

    // Accumulate Leq sum
    Leq_sum_sqr += q.sum_sqr_weighted;
    Leq_samples += SAMPLES_SHORT;

    // When we gather enough samples, calculate new Leq value
    if (Leq_samples >= SAMPLE_RATE * LEQ_PERIOD) {
      double Leq_RMS = sqrt(Leq_sum_sqr / Leq_samples);
      Leq_dB = MIC_OFFSET_DB + MIC_REF_DB + 20 * log10(Leq_RMS / MIC_REF_AMPL);
      Leq_sum_sqr = 0;
      Leq_samples = 0;
      
      // Serial output, customize (or remove) as needed
      Serial.printf("%.1f\n", Leq_dB);

      // Debug only
      //Serial.printf("%u processing ticks\n", q.proc_ticks);
    }

    
  }
}

void loop() {
  // Nothing here..
}```

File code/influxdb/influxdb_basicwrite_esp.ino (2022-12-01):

#if defined(ESP32)
#include <WiFiMulti.h>
WiFiMulti wifiMulti;
#define DEVICE "ESP32"
#elif defined(ESP8266)
#include <ESP8266WiFiMulti.h>
ESP8266WiFiMulti wifiMulti;
#define DEVICE "ESP8266"
#endif

#include <InfluxDbClient.h>
#include <InfluxDbCloud.h>

// Import the sensor librarys, and set some constants
#include "Adafruit_VEML7700.h"
#include "Adafruit_AS7341.h"
#include "Adafruit_SHTC3.h"
#include "Adafruit_DPS310.h"
#include <Adafruit_SGP30.h>

Adafruit_AS7341 as7341;
Adafruit_VEML7700 veml = Adafruit_VEML7700();
Adafruit_DPS310 dps;
Adafruit_SHTC3 shtc3 = Adafruit_SHTC3();
Adafruit_SGP30 sgp;
Adafruit_Sensor *dps_temp = dps.getTemperatureSensor();
Adafruit_Sensor *dps_pressure = dps.getPressureSensor();


// WiFi AP SSID
#define WIFI_SSID "Ziggo3166762"
// WiFi password
#define WIFI_PASSWORD "ddnj5TqJchkr"
// InfluxDB v2 server url, e.g. https://eu-central-1-1.aws.cloud2.influxdata.com (Use: InfluxDB UI -> Load Data -> Client Libraries)
#define INFLUXDB_URL "https://westeurope-1.azure.cloud2.influxdata.com"
// InfluxDB v2 server or cloud API authentication token (Use: InfluxDB UI -> Data -> Tokens -> <select token>)
#define INFLUXDB_TOKEN "bMICiv8IfTZJpLlICxWTu0HZ_9Pk8He5csVmoXMaHSYnrpQ-bhmgSPtwsfcGf7k7isd-oOTjlv0XuuIQc_v3QA=="
// InfluxDB v2 organization id (Use: InfluxDB UI -> User -> About -> Common Ids )
#define INFLUXDB_ORG "chiel_hoogenkamp@hotmail.com"
// InfluxDB v2 bucket name (Use: InfluxDB UI ->  Data -> Buckets)
#define INFLUXDB_BUCKET "moodsense"

// Set timezone string according to https://www.gnu.org/software/libc/manual/html_node/TZ-Variable.html
// Examples:
//  Pacific Time: "PST8PDT"
//  Eastern: "EST5EDT"
//  Japanesse: "JST-9"
//  Central Europe: "CET-1CEST,M3.5.0,M10.5.0/3"
#define TZ_INFO "CET-1CEST,M3.5.0,M10.5.0/3"

// InfluxDB client instance with preconfigured InfluxCloud certificate
InfluxDBClient client(INFLUXDB_URL, INFLUXDB_ORG, INFLUXDB_BUCKET, INFLUXDB_TOKEN, InfluxDbCloud2CACert);

// Data point
Point sensor("omgevingsparameters");

//recieve serial messages from arduino nano 33 ble sense
#define RXp2 16
#define TXp2 17

void setup() {
  Serial.begin(115200);
  Serial2.begin(115200, SERIAL_8N1, RXp2, TXp2);

  // Initialize the sensors
  as7341.begin();
  dps.begin_I2C();
  shtc3.begin();
  veml.begin();
  sgp.begin();

  Serial.print(F("Gain: "));
  switch (veml.getGain()) {
    case VEML7700_GAIN_1: Serial.println("1"); break;
    case VEML7700_GAIN_2: Serial.println("2"); break;
    case VEML7700_GAIN_1_4: Serial.println("1/4"); break;
    case VEML7700_GAIN_1_8: Serial.println("1/8"); break;
  }

  Serial.print(F("Integration Time (ms): "));
  switch (veml.getIntegrationTime()) {
    case VEML7700_IT_25MS: Serial.println("25"); break;
    case VEML7700_IT_50MS: Serial.println("50"); break;
    case VEML7700_IT_100MS: Serial.println("100"); break;
    case VEML7700_IT_200MS: Serial.println("200"); break;
    case VEML7700_IT_400MS: Serial.println("400"); break;
    case VEML7700_IT_800MS: Serial.println("800"); break;
  }

  dps.configurePressure(DPS310_64HZ, DPS310_64SAMPLES);
  dps.configureTemperature(DPS310_64HZ, DPS310_64SAMPLES);
  as7341.setATIME(100);
  as7341.setASTEP(999);
  as7341.setGain(AS7341_GAIN_256X);

  // Setup wifi
  WiFi.mode(WIFI_STA);
  wifiMulti.addAP(WIFI_SSID, WIFI_PASSWORD);

  Serial.print("Connecting to wifi");
  while (wifiMulti.run() != WL_CONNECTED) {
    Serial.print(".");
    delay(100);
  }
  Serial.println();

  // Add tags
  sensor.addTag("device", DEVICE);
//  sensor.addTag("SGP30_TVOC", sgp.TVOC );

  // Accurate time is necessary for certificate validation and writing in batches
  // For the fastest time sync find NTP servers in your area: https://www.pool.ntp.org/zone/
  // Syncing progress and the time will be printed to Serial.
  timeSync(TZ_INFO, "pool.ntp.org", "time.nis.gov");

  // Check server connection
  if (client.validateConnection()) {
    Serial.print("Connected to InfluxDB: ");
    Serial.println(client.getServerUrl());
  } else {
    Serial.print("InfluxDB connection failed: ");
    Serial.println(client.getLastErrorMessage());
  }
}

void loop() {

  uint16_t TVOC, eCO2, rawH2, rawEthanol;
  uint16_t readings[12];
  sensors_event_t temp_event, pressure_event;
  dps.getEvents(&temp_event, &pressure_event);
  sensors_event_t humidity, temp;
  shtc3.getEvent(&humidity, &temp);
  
  // Clear fields for reusing the point. Tags will remain untouched
  sensor.clearFields();

 //initializeer alle sensor metingen
//  if (! sgp.IAQmeasure()&& !as7341.readAllChannels(readings)&& !dps.temperatureAvailable() || !dps.pressureAvailable()&& ! sgp.IAQmeasureRaw()) {
//  Serial.println("Measurements failed");
//  return;

 (sgp.IAQmeasure()&& as7341.readAllChannels(readings)&& dps.pressureAvailable()&& sgp.IAQmeasureRaw());
    
  // Store measured value into point
  // Report RSSI of currently connected network
  sensor.addField("rssi", WiFi.RSSI());
  sensor.addField("TVOC", sgp.TVOC);
  sensor.addField("eCO2", sgp.eCO2);
  sensor.addField("rawH2", sgp.rawH2);
  sensor.addField("rawEthanol",sgp.rawEthanol);
  sensor.addField("violet", readings[0]);
  sensor.addField("indigo", readings[1]);
  sensor.addField("blauw", readings[2]);
  sensor.addField("cyaan", readings[3]);
  sensor.addField("groen", readings[6]);
  sensor.addField("geel", readings[7]);
  sensor.addField("oranje", readings[8]);
  sensor.addField("rood", readings[9]);
  sensor.addField("NIR", readings[11]);
  sensor.addField("lux", veml.readLux());
  sensor.addField("ALS", veml.readALS());
  sensor.addField("pressure", pressure_event.pressure);
  sensor.addField("temperatuur", temp.temperature);
  sensor.addField("luchtvochtigheid", humidity.relative_humidity );
  sensor.addField("ML classificatie", Serial2.readString() );
  

  // Print what are we exactly writing
  Serial.print("Writing: ");
  Serial.println(sensor.toLineProtocol());

  // If no Wifi signal, try to reconnect it
  if ((WiFi.RSSI() == 0) && (wifiMulti.run() != WL_CONNECTED)) {
    Serial.println("Wifi connection lost");
  }

  // Write point
  if (!client.writePoint(sensor)) {
    Serial.print("InfluxDB write failed: ");
    Serial.println(client.getLastErrorMessage());
  }

  //Wait 10s
  Serial.println("Wait 10s");
  delay(10000);
}

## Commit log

2023-02-07 Create arduino sketch
2023-02-11 Create ESC-50 metadata.csv
    [ESC-50 metadata.csv]
2023-02-11 Create sound classifiction with ESC-50.ipynb
2023-02-16 Update sound classifiction with ESC-50.ipynb
